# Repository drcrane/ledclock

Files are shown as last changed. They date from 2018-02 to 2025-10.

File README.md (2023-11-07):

LEDCLOCK
========

This repository contains the source files for my seven segment LED
Clock which I made in 2017 for my nephew.

The Clock is powered by an MSP430G2553 and a 32.768 kHz watch
crystal. The clock queried time over the serial port which should
be connected to an ESP8266 (ESP-01) running a modified terminal
programme that supports querying internet time servers.

Running ntpd on Alpine Linux
----------------------------

Turn on a time server in Alpine Linux / busybox (if compiled in)

    busybox ntpd -l -d -d -d -n

This is good for testing as you can see each request for the time.

ESP8266\_RTOS\_SDK
------------------

`esp8266terminal2` uses the espressif SDK, please see readme file
in `esp8266terminal2`.

 - Benjamin Green 2021-12-31

Open-RTOS-SDK
-------------

`esp8266terminal` is no longer used for this project and will be
removed soon. Please use `esp8266terminal2`.

The terminal application was modified (not very well) to support
this application. The REPOs:

repo:   https://github.com/SuperHouse/esp-open-rtos
commit: 46499c0f26c490f5a539f82eb950fa7879f65dc7

repo:   https://github.com/pfalcon/esp-open-sdk
commit: 5518fb6116c35a02ccb9a87260bb194a57cb429e

The build scripts and programmer are required from the above
repos.

The modified terminal application is available in:
`esp8266terminal` I recommend that you copy this into the
`esp-open-rtos/examples` directory to compile and deploy to
an ESP8266.

 - Benjamin Green 2018-02-03

Web Interface Time Setting
--------------------------

To set the time for a clock that currently has an IP address of `192.168.0.128`

    curl -v -d time_to_set=23:50:00 http://192.168.0.128/wifi

A browser may also be used by accessing the page at: `http://192.168.0.128/wifi`.

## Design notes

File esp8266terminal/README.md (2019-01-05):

# Terminal Application

This terminal application contains support for setting the
WiFi SSID and PSK along with the ability to query an arbitrary
internet time server for the current time over serial at 9600.
It was modified for use with the LEDCLOCK project.

## To build this thing....

export PATH=/path_to/esp-open-sdk/xtensa-lx106-elf/bin:$PATH

make ESPPORT=/dev/ttyUSB0 flash

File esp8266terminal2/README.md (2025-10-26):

Terminal Interface for ESP8266 (ESP-01S)
========================================

This is an enhanced version of esp8266terminal which compiles with the
`ESP8266_RTOS_SDK` from espressif.

Setup
-----

To compile the source, download the compiler toolchain:

    xtensa-lx106-elf-gcc8_4_0-esp-2020r3-linux-amd64.tar.gz

And the version of the `ESP8266_RTOS_SDK` you would like to use (for
developing this application version 3.4 was used):

    ESP8266_RTOS_SDK-v3.4.zip

Download URLs:

* [Github Repository RTOS SDK](https://github.com/espressif/ESP8266_RTOS_SDK)
* [xtensa GCC toolchain](https://dl.espressif.com/dl/xtensa-lx106-elf-gcc8_4_0-esp-2020r3-linux-amd64.tar.gz)
* [ESP8266\_RTOS\_SDK](https://github.com/espressif/ESP8266_RTOS_SDK/releases/download/v3.4/ESP8266_RTOS_SDK-v3.4.zip)

Make a workspace directory (for this document ~/esp8266 is assumed) and
extract the contents of the SDK and compiler toolchain:

    mkdir ~/esp8266
    cd ~/esp8266
    # download the files or alter the path as required
    tar -xf xtensa-lx106-elf-gcc8_4_0-esp-2020r3-linux-amd64.tar.gz
    unzip ESP8266_RTOS_SDK-v3.4.zip

Set the required environment variables (this assumes `ash` or `bash`):

    export PATH=~/esp8266/xtensa-lx106-elf/bin:$PATH
    export IDF_PATH=~/esp8266/ESP8266_RTOS_SDK

Now attempt to compile the code:

    cd ~/esp8266/ledclock/esp8266terminal2
    make

This will likely fail since python modules are required

Additional Notes
----------------

`partitions.csv` is a copy of `partitions_singleapp.csv` from the SDK.

Communication using `picocom`
-----------------------------

`picocom` is a useful mini utility that allows serial communication,
it is like minicom but more modern. However, it does not seem to
compile properly on Alpine / musl when one wishes to use custom baud
rates. Custom rates are important for being able to view the early
output sent from an ESP8266 (ESP-01), the device used in my project.

The `setserial` application does work with musl and so to interact
with the device on `/dev/ttyUSB0` at 74880 bps:

    ./setserial /dev/ttyUSB0 74880
    doas ./picocom --noinit --noreset --omap crcrlf /dev/ttyUSB0

`picocom` will probably report that the baud rate is 9600, this can
be safely ignored, the `--noinit` switch will prevent changes to
the rate when the application starts. **IMPORTANT** this also
assumes that the other settings are normal, such as: 8-N-1. That is
to say: 8 data bits, no parity bit and 1 stop bit.

For more detail and to set other options, see the `stty` command.

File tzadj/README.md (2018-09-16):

# Create some Timezone Data for the LED Clock

This is a simple program that creates two numbers per year
the two numbers indicate the start and end of a daylight
saving time in Unix epoch time.

The database is available from:

    https://www.iana.org/time-zones

The one I used is:

    https://data.iana.org/time-zones/releases/tzdb-2018e.tar.lz

## `build.sh`

Running `build.sh` should give this output:

    1711846900 Add an hour? Yes
    2045696401 Add an hour? No
    1887843601 Add an hour? No

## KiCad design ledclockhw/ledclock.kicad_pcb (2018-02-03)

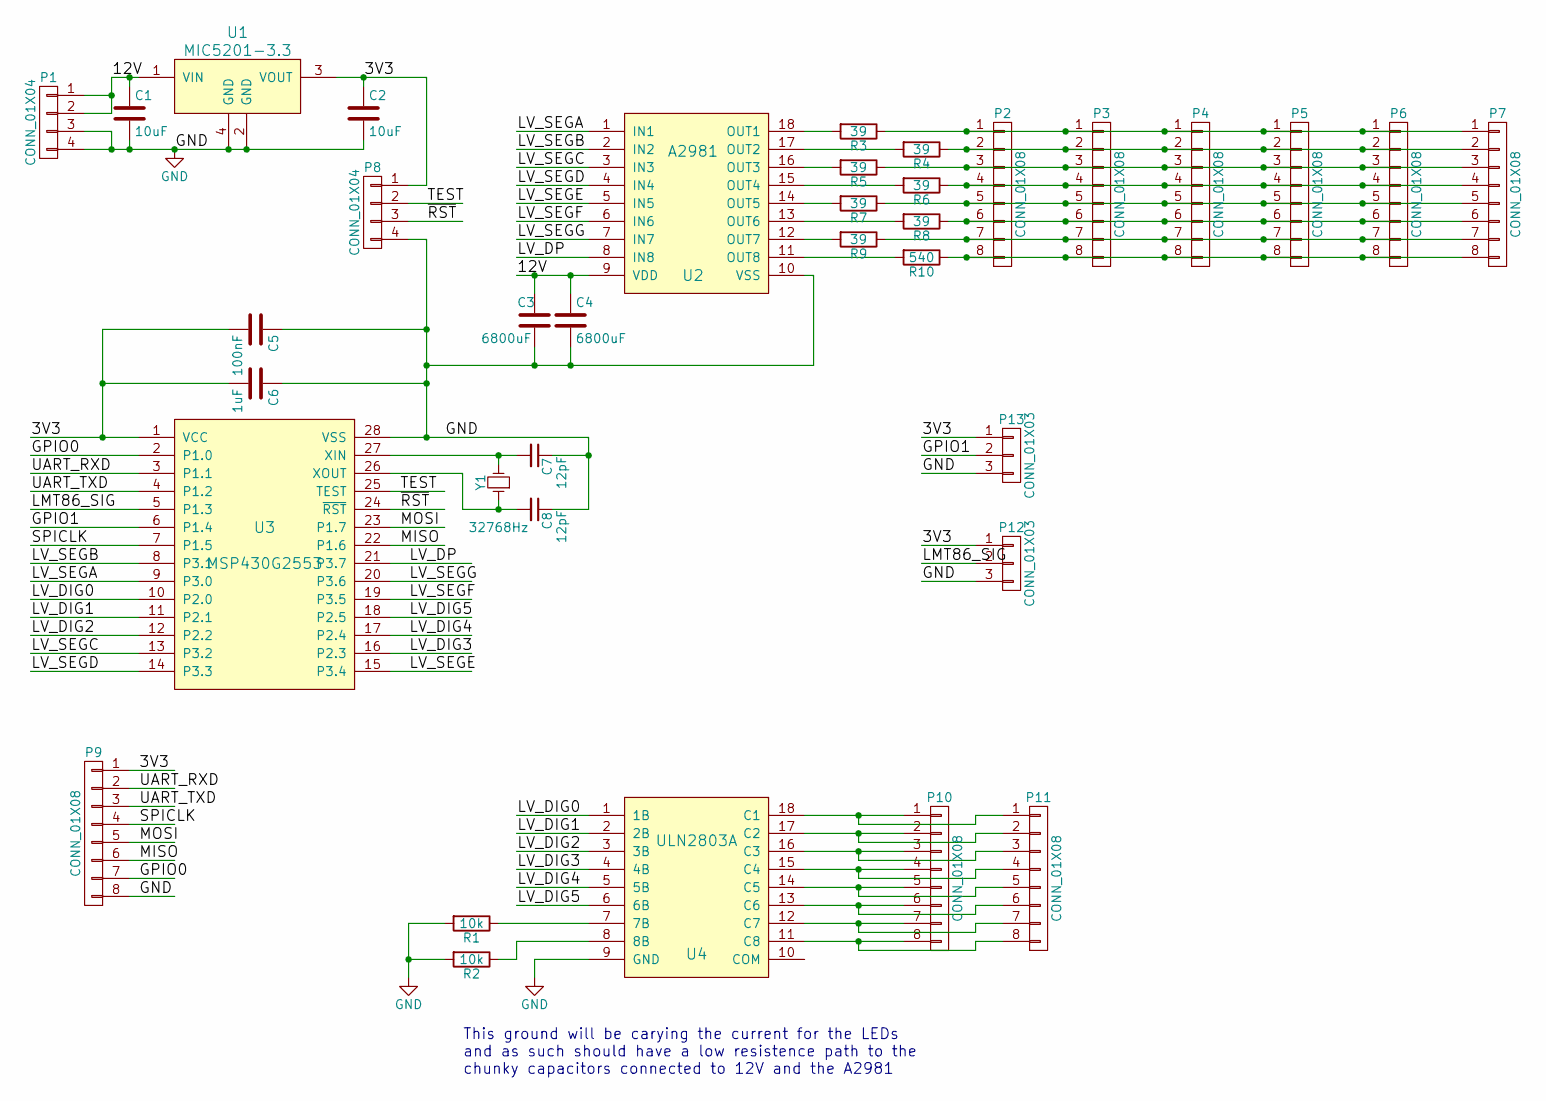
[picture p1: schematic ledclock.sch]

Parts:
C1, C2: 10uF; C_1210
C3, C4: 6800uF; CP_Radial_D18.0mm_P7.50mm
C5: 100nF; C_0603
C6: 1uF; C_0805
C7, C8: 12pF; C_0603
P1, P8: CONN_01X04; Molex_KK-6410-04_04x2.54mm_Straight
P2, P3, P4, P5, P6, P7, P9, P10, P11: CONN_01X08; Molex_KK-6410-08_08x2.54mm_Straight
P12, P13: CONN_01X03; Molex_KK-6410-03_03x2.54mm_Straight
R1, R2: 10k; R_0603
R3, R4, R5, R6, R7, R8, R9: 39; R_1206
R10: 540; R_1206
U1: MIC5201-3.3; SOT-223
U2: A2981; DIP-18_W7.62mm
U3: MSP430G2553; TSSOP-28_4.4x9.7mm_Pitch0.65mm
U4: ULN2803A; DIP-18_W7.62mm
Y1: 32768Hz; Crystal_C38-LF_d3.0mm_l8.0mm_Horizontal

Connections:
/3V3: C2.1, C5.2, C6.2, P8.1, P9.1, P12.1, P13.1, U1.3 (VOUT), U3.1 (VCC)
/12V: C1.1, C3.1, C4.1, P1.1, P1.2, U1.1 (VIN), U2.9 (VDD)
/GPIO0: P9.7, U3.2 (P1.0)
/GPIO1: P13.2, U3.6 (P1.4)
/LMT86_SIG: P12.2, U3.5 (P1.3)
/LV_DIG0: U3.10 (P2.0), U4.1 (1B)
/LV_DIG1: U3.11 (P2.1), U4.2 (2B)
/LV_DIG2: U3.12 (P2.2), U4.3 (3B)
/LV_DIG3: U3.16 (P2.3), U4.4 (4B)
/LV_DIG4: U3.17 (P2.4), U4.5 (5B)
/LV_DIG5: U3.18 (P2.5), U4.6 (6B)
/LV_DP: U2.8 (IN8), U3.21 (P3.7)
/LV_SEGA: U2.1 (IN1), U3.9 (P3.0)
/LV_SEGB: U2.2 (IN2), U3.8 (P3.1)
/LV_SEGC: U2.3 (IN3), U3.13 (P3.2)
/LV_SEGD: U2.4 (IN4), U3.14 (P3.3)
/LV_SEGE: U2.5 (IN5), U3.15 (P3.4)
/LV_SEGF: U2.6 (IN6), U3.19 (P3.5)
/LV_SEGG: U2.7 (IN7), U3.20 (P3.6)
/MISO: P9.6, U3.22 (P1.6)
/MOSI: P9.5, U3.23 (P1.7)
/SPICLK: P9.4, U3.7 (P1.5)
/TEST: P8.2, U3.25 (TEST)
/UART_RXD: P9.2, U3.3 (P1.1)
/UART_TXD: P9.3, U3.4 (P1.2)
/~RST: P8.3, U3.24 (~RST)
GND: C1.2, C2.2, C3.2, C4.2, C5.1, C6.1, C7.1, C8.1, P1.3, P1.4, P8.4, P9.8, P12.3, P13.3, R1.2, R2.2, U1.2 (GND), U1.4 (GND), U2.10 (VSS), U3.28 (VSS), U4.9 (GND)
unnamed: C7.2, U3.27 (XIN), Y1.2
unnamed: C8.2, U3.26 (XOUT), Y1.1
unnamed: P2.1, P3.1, P4.1, P5.1, P6.1, P7.1, R3.1
unnamed: P2.2, P3.2, P4.2, P5.2, P6.2, P7.2, R4.1
unnamed: P2.3, P3.3, P4.3, P5.3, P6.3, P7.3, R5.1
unnamed: P2.4, P3.4, P4.4, P5.4, P6.4, P7.4, R6.1
unnamed: P2.5, P3.5, P4.5, P5.5, P6.5, P7.5, R7.1
unnamed: P2.6, P3.6, P4.6, P5.6, P6.6, P7.6, R8.1
unnamed: P2.7, P3.7, P4.7, P5.7, P6.7, P7.7, R9.1
unnamed: P2.8, P3.8, P4.8, P5.8, P6.8, P7.8, R10.1
unnamed: P10.1, P11.1, U4.18 (C1)
unnamed: P10.2, P11.2, U4.17 (C2)
unnamed: P10.3, P11.3, U4.16 (C3)
unnamed: P10.4, P11.4, U4.15 (C4)
unnamed: P10.5, P11.5, U4.14 (C5)
unnamed: P10.6, P11.6, U4.13 (C6)
unnamed: P10.7, P11.7, U4.12 (C7)
unnamed: P10.8, P11.8, U4.11 (C8)
unnamed: R1.1, U4.7 (7B)
unnamed: R2.1, U4.8 (8B)
unnamed: R3.2, U2.18 (OUT1)
unnamed: R4.2, U2.17 (OUT2)
unnamed: R5.2, U2.16 (OUT3)
unnamed: R6.2, U2.15 (OUT4)
unnamed: R7.2, U2.14 (OUT5)
unnamed: R8.2, U2.13 (OUT6)
unnamed: R9.2, U2.12 (OUT7)
unnamed: R10.2, U2.11 (OUT8)

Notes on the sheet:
This ground will be carying the current for the LEDs and as such should have a low resistence path to the chunky capacitors connected to 12V and the A2981

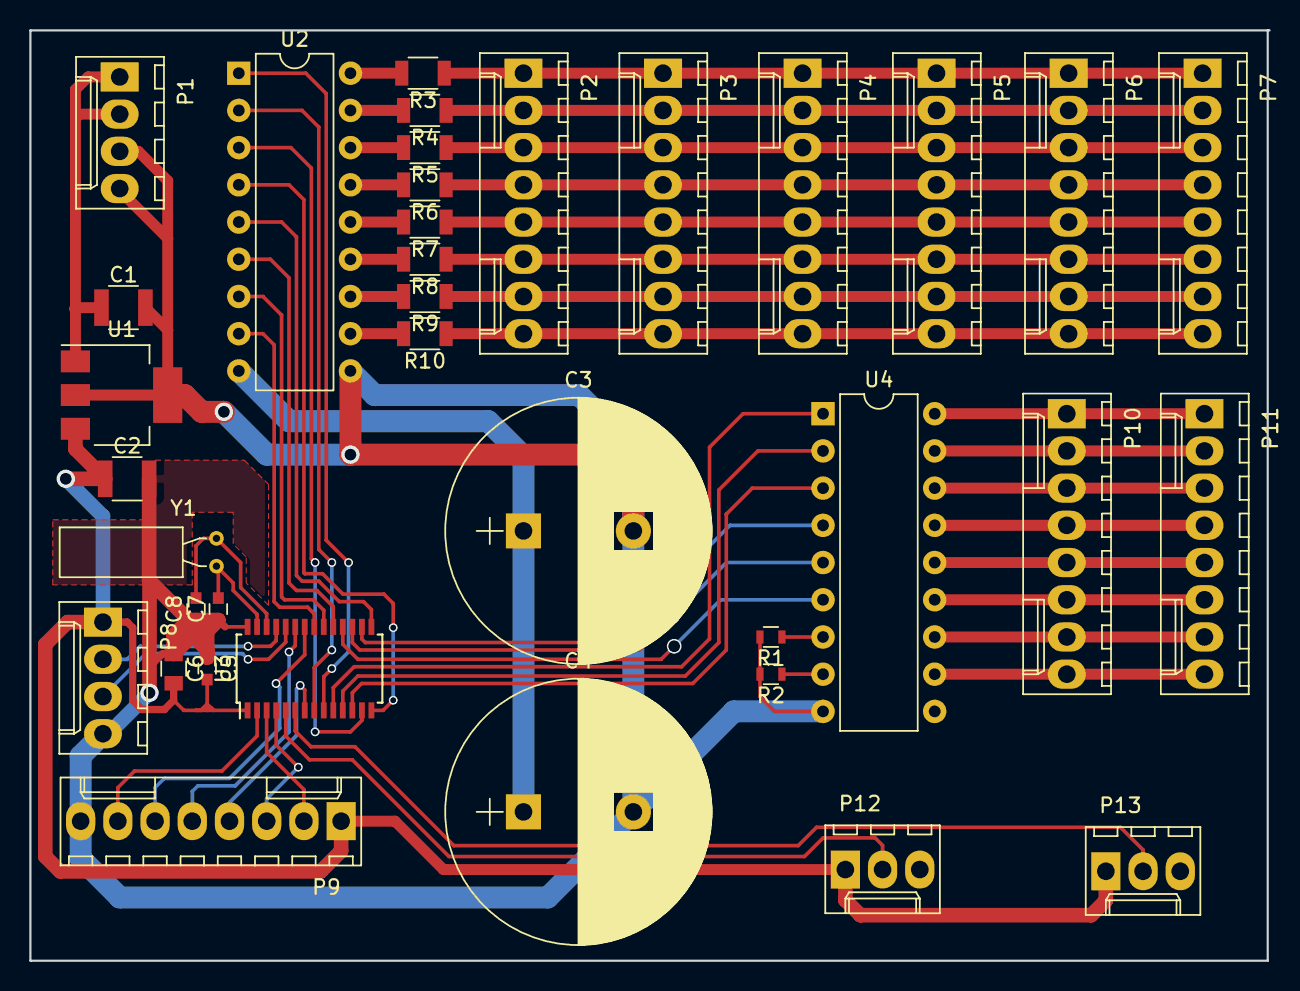
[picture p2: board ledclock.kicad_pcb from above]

Board: 2 copper layers, 84.6 x 63.5 mm, 36 parts (0 on the bottom side), 55 nets.

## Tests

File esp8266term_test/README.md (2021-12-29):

Testing Suite
=============

To run tests for this project the computer must have the standard toolset
installed:

* `make`
* `gcc`
* `valgrind` (optional)
* `busybox`

To compile and run all the tests:

    make test

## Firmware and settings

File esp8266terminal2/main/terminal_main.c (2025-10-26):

/*
   Terminal Interface to ESP8266

   This example code is in the Public Domain (or CC0 licensed, at your option.)

   Unless required by applicable law or agreed to in writing, this
   software is distributed on an "AS IS" BASIS, WITHOUT WARRANTIES OR
   CONDITIONS OF ANY KIND, either express or implied.
*/
#include <stdio.h>
#include <string.h>
#include "freertos/FreeRTOS.h"
#include "freertos/task.h"
#include "freertos/event_groups.h"
#include "esp_system.h"
#include "esp_spi_flash.h"
#include "driver/uart.h"
#include "esp_wifi.h"
#include "esp_event_loop.h"
#include "nvs.h"
#include "nvs_flash.h"
#include "lwip/sockets.h"
#include "lwip/api.h"

#include "argparser.h"

static const char * TAG = "terminal";

static TimerHandle_t system_monitor_timer;

typedef nvs_handle nvs_handle_t;
static nvs_handle_t nvs_config_handle;

static EventGroupHandle_t wifi_event_group;
#define CONNECTED_BIT BIT0
#define CONNECTION_FAILED BIT1

static ip_addr_t sta_ip_addr;
static struct netconn * tcp_server_handle;

static void wifi_event_handler(void * arg, esp_event_base_t event_base, int32_t event_id, void * event_data) {
	if (event_base == WIFI_EVENT) {
		if (event_id == WIFI_EVENT_STA_START) {
			esp_wifi_connect();
		} else
		if (event_id == WIFI_EVENT_STA_DISCONNECTED) {
			// SET CONNECTION FAILED BIT...
			xEventGroupClearBits(wifi_event_group, CONNECTED_BIT);
		}
	} else
	if (event_base == IP_EVENT) {
		if (event_id == IP_EVENT_STA_GOT_IP) {
			ip_event_got_ip_t * ip_event = (ip_event_got_ip_t *)event_data;
			ESP_LOGI(TAG, "got ip: %s", ip4addr_ntoa(&ip_event->ip_info.ip));
			sta_ip_addr = ip_event->ip_info.ip;
			xEventGroupSetBits(wifi_event_group, CONNECTED_BIT);
		}
	}
}

#define WIFI_STA_CONNECTING 1
#define WIFI_STA_CONNECTED 2
#define WIFI_STA_ERROR 4

#define WIFI_AP_ERROR 8

static int wifi_sta_join() {
	esp_err_t rc = ESP_OK;
	wifi_mode_t wifi_mode;
	// Is it already connected?
	int bits = xEventGroupGetBits(wifi_event_group);
	if (bits & CONNECTED_BIT) {
		return WIFI_STA_CONNECTED;
	}
	rc = esp_wifi_get_mode(&wifi_mode);
	if (rc == ESP_OK && !(wifi_mode & WIFI_MODE_STA)) {
		rc = esp_wifi_set_mode(wifi_mode | WIFI_MODE_STA);
	}
	{
		// Is there an ssid set?
		wifi_config_t wifi_config = { 0 };
		size_t len = sizeof(wifi_config.sta.ssid);
		rc = nvs_get_str(nvs_config_handle, "sta.ssid", (char *)(wifi_config.sta.ssid), &len);
		if (rc != ESP_OK) {
			ESP_LOGI(TAG, "sta ssid read error");
			return WIFI_STA_ERROR;
		}
		len = sizeof(wifi_config.sta.password);
		rc = nvs_get_str(nvs_config_handle, "sta.pwd", (char *)wifi_config.sta.password, &len);
		if (rc != ESP_OK) {
			ESP_LOGI(TAG, "sta pwd read error");
			return WIFI_STA_ERROR;
		}
		rc = esp_wifi_set_config(ESP_IF_WIFI_STA, &wifi_config);
		if (rc != ESP_OK) {
			ESP_LOGI(TAG, "sta set config error %d", rc);
			return WIFI_STA_ERROR;
		}
	}
	// begin new connect if wifi was in sta mode otherwise the
	// callback function will perform the connect call
	if (rc == ESP_OK && (wifi_mode & WIFI_MODE_STA)) {
		rc = esp_wifi_connect();
	}
	if (rc != ESP_OK) {
		ESP_LOGI(TAG, "error at end");
		return WIFI_STA_ERROR;
	}
	return WIFI_STA_CONNECTING;
}

static int wifi_softap_start() {
	esp_err_t rc = ESP_OK;
	{
	wifi_config_t wifi_config = { 0 };
	size_t len = sizeof(wifi_config.ap.ssid);
	rc = nvs_get_str(nvs_config_handle, "ap.ssid", (char *)(wifi_config.sta.ssid), &len);
	if (rc != ESP_OK) {
		ESP_LOGI(TAG, "ap ssid read error");
		return WIFI_AP_ERROR;
	}
	}
	//
	return 0;
}

static struct netconn * tcp_client_handle;
static int tcp_client_data_waiting;

static void tcp_server_callback(struct netconn * conn, enum netconn_evt evt, uint16_t length) {
	ESP_LOGI(TAG, "tcp_cb: %d %u", evt, length);
	if (evt == NETCONN_EVT_RCVPLUS) {
		//struct netbuf * netbuf;
		//void * ptr;
		//uint16_t datalen;
		//err_t err;
		if (conn == tcp_server_handle) {
			ESP_LOGI(TAG, "tcp_server_handle");
		} else
		if (conn == tcp_client_handle) {
			//if (length > 0) {
				ESP_LOGI(TAG, "new client data");
				tcp_client_data_waiting ++;
			//}
		} else {
			ESP_LOGI(TAG, "unknown client data");
			tcp_client_data_waiting ++;
		}
		// Don't think can call in callback.
		//err = netconn_accept(conn, &tcp_client_handle);
		//ESP_LOGI(TAG, "netconn_accept err = %d", err);
		/*
		if (conn == tcp_server_handle && netconn_accept(conn, &tcp_client_handle) == ERR_OK) {
			ESP_LOGI(TAG, "got new connection");
		} else
		if (conn == tcp_client_handle && netconn_recv(conn, &netbuf) == ERR_OK) {
			ESP_LOGI(TAG, "recv_ok");
			do {
				netbuf_data(netbuf, (void *)&ptr, &datalen);
				ESP_LOGI(TAG, "%d", (int)datalen);
			} while (netbuf_next(netbuf) >= 0);
			netbuf_delete(netbuf);
		} else {
			ESP_LOGI(TAG, "got something %d %u", (int)evt, length);
		}
		*/
	}
}

static void system_monitor_callback(TimerHandle_t xTimer) {
	int rc = wifi_sta_join();
	{
		char buf[32];
		sprintf(buf, "wifi_sta_join() %d\r\n", rc);
		uart_write_bytes(UART_NUM_0, buf, strlen(buf));
	}
	if (rc == WIFI_STA_CONNECTED) {
		err_t err;
		struct netbuf * netbuf;
		void * ptr;
		uint16_t datalen;
		if (tcp_server_handle == NULL) {
			// begin listening
			// esp_err_t tcpip_adapter_get_ip_info(tcpip_adapter_if_t tcpip_if, tcpip_adapter_ip_info_t *ip_info);
			//ip_addr_t ip_any = IP_ADDR_ANY;
			tcp_server_handle = netconn_new_with_callback(NETCONN_TCP, tcp_server_callback);
			ESP_LOGI(TAG, "%d", tcp_server_handle == NULL ? 0 : 1);
			netconn_set_flags(tcp_server_handle, NETCONN_FLAG_NON_BLOCKING);
			// Don't need to use htons here... for some reason.
			err = netconn_bind(tcp_server_handle, IP_ADDR_ANY, 5000);
			ESP_LOGI(TAG, "bind err %d", err);
			err = netconn_listen_with_backlog(tcp_server_handle, 2);
			ESP_LOGI(TAG, "listen err %d", err);
			tcp_client_handle = NULL;
		}
		if (tcp_server_handle != NULL) {
			struct netconn * client_conn;
			err = netconn_accept(tcp_server_handle, &client_conn);
			if (err == ERR_WOULDBLOCK) {
				ESP_LOGI(TAG, "would block here");
			} else
			if (err == ERR_OK) {
				tcp_client_data_waiting = 0;
				tcp_client_handle = client_conn;
				ESP_LOGI(TAG, "accepted connection");
			} else {
				ESP_LOGI(TAG, "netconn_accept err = %d", err);
				if (tcp_client_handle) {
					netconn_delete(tcp_client_handle);
					tcp_client_handle = NULL;
				}
			}
		}
		if (tcp_client_handle) {
			ESP_LOGI(TAG, "accept complete");
			if (tcp_client_data_waiting) {
				ESP_LOGI(TAG, "data waiting");
				if ((err = netconn_recv(tcp_client_handle, &netbuf)) == ERR_OK) {
					do {
						netbuf_data(netbuf, (void **)&ptr, &datalen);
						ESP_LOGI(TAG, "got data %d", (int)datalen);
					} while (netbuf_next(netbuf) >= 0);
					netbuf_delete(netbuf);
				//	tcp_client_data_waiting = 0;
				//} else
				//if (err == ERR_WOULDBLOCK) {
				//	ESP_LOGI(TAG, "still connected");
				//} else {
				//	ESP_LOGI(TAG, "connection closed");
				//	netconn_close(tcp_client_handle);
					//	netconn_delete(tcp_client_handle);
				//	tcp_client_handle = NULL;
				//	tcp_client_data_waiting --;
				} else {
					ESP_LOGI(TAG, "recv err = %d", err);
					netconn_close(tcp_client_handle);
					netconn_delete(tcp_client_handle);
					tcp_client_handle = NULL;
					//tcp_client_data_waiting = 0;
				}
				tcp_client_data_waiting --;
			}
		}
	}
	/*
	switch (rc) {
	case WIFI_RC_CONNECTING:
	case WIFI_RC_CONNECTED:
	case WIFI_RC_ERROR:
	default:
	}
	*/
}

static void command_process(int argc, char *argv[]) {
	esp_err_t err;
	if (strcmp(argv[0], "wifi") == 0) {
		//if (argc >= 3 && strcmp(argv[1], "config") == 0) {
			//if (strcmp(argv[2], "dump") == 0) {
			//	wifi_config_t config = {0};
			//	err = esp_wifi_get_config(ESP_IF_WIFI_STA, &config);
			//	if (err != ESP_OK) {
			//		uart_write_bytes(UART_NUM_0, "ERR\r\n", 5);
			//		return;
			//	}
			//	uart_write_bytes(UART_NUM_0, (char *)config.sta.ssid, strlen((char *)config.sta.ssid));
			//	uart_write_bytes(UART_NUM_0, "\r\n", 2);
			//}
		//} else
		if (strcmp(argv[1], "join") == 0) {
			wifi_sta_join();
			//int timeout_ms = 10000;
			//wifi_mode_t wifi_mode = WIFI_MODE_NULL;
			//if (esp_wifi_get_mode(&wifi_mode) == ESP_OK && wifi_mode != WIFI_MODE_STA && wifi_mode != WIFI_MODE_APSTA) {
			//	ESP_ERROR_CHECK(esp_wifi_set_mode(WIFI_MODE_STA));
			//} else {
			//}
			//if (argc == 4) {
			//	//strncpy((char *)wifi_config.sta.ssid, argv[2], sizeof(wifi_config.sta.ssid));
			//	//strncpy((char *)wifi_config.sta.password, argv[3], sizeof(wifi_config.sta.password));
			//	//ESP_ERROR_CHECK(esp_wifi_set_config(ESP_IF_WIFI_STA, &wifi_config));
			//}
			//if (wifi_mode == WIFI_MODE_STA || wifi_mode == WIFI_MODE_APSTA) {
			//	ESP_ERROR_CHECK(esp_wifi_connect());
			//} else {
			//}
			//int bits = xEventGroupWaitBits(wifi_event_group, CONNECTED_BIT,
			//		pdFALSE, pdFALSE, timeout_ms / portTICK_PERIOD_MS);
			//if (bits & CONNECTED_BIT) {
			//	uart_write_bytes(UART_NUM_0, "CON\r\n", 5);
			//} else {
			//	uart_write_bytes(UART_NUM_0, "TOC\r\n", 5);
			//}
		} else
		if (strcmp(argv[1], "status") == 0) {
			int bits = xEventGroupGetBits(wifi_event_group);
			if (bits & CONNECTED_BIT) {
				uart_write_bytes(UART_NUM_0, "CON\r\n", 5);
			} else {
				uart_write_bytes(UART_NUM_0, "DIS\r\n", 5);
			}
		} else
		if (argc == 4 && strcmp(argv[1], "on") == 0) {
			uart_write_bytes(UART_NUM_0, "wifion?\r\n", 9);
		} else {
			uart_write_bytes(UART_NUM_0, "eh?\r\n", 5);
		}
	} else
	if (strcmp(argv[0], "set") == 0) {
		/*
		if (argc == 3) {
		if (strcmp(argv[1], "ssid") == 0) {
		}
		if (strcmp(argv[1], "pwd") == 0) {
		}
		}
		*/
		if (argc == 4) {
			if (strcmp(argv[1], "stacred") == 0) {
				err = nvs_set_str(nvs_config_handle, "sta.ssid", argv[2]);
				if (err == ESP_OK) {
					err = nvs_set_str(nvs_config_handle, "sta.pwd", argv[3]);
				}
				if (err == ESP_OK) {
					uart_write_bytes(UART_NUM_0, "OK_\r\n", 5);
				} else {
					uart_write_bytes(UART_NUM_0, "ERR\r\n", 5);
				}
			} else
			if (strcmp(argv[1], "apcred") == 0) {
				err = nvs_set_str(nvs_config_handle, "ap.ssid", argv[2]);
				if (err == ESP_OK) {
					err = nvs_set_str(nvs_config_handle, "ap.pwd", argv[3]);
				}
				if (err == ESP_OK) {
					uart_write_bytes(UART_NUM_0, "OK_\r\n", 5);
				} else {
					uart_write_bytes(UART_NUM_0, "ERR\r\n", 5);
				}
			}
		}
	} else
	if (strcmp(argv[0], "get") == 0) {
		if (argc == 1) {
			size_t len = 32;
			char buf[32];
			uart_write_bytes(UART_NUM_0, "STA\r\n", 5);
			err = nvs_get_str(nvs_config_handle, "sta.ssid", buf, &len);
			if (err == ESP_OK) {
				uart_write_bytes(UART_NUM_0, buf, len);
				uart_write_bytes(UART_NUM_0, "\r\n", 2);
			}
			len = 32;
			err = nvs_get_str(nvs_config_handle, "sta.pwd", buf, &len);
			if (err == ESP_OK) {
				uart_write_bytes(UART_NUM_0, buf, len);
				uart_write_bytes(UART_NUM_0, "\r\n", 2);
			}
			uart_write_bytes(UART_NUM_0, "AP_\r\n", 5);
		}
		if (argc == 2) {
			if (strcmp(argv[1], "stacred") == 0) {
				size_t len = 29;
				char buf[32];
				err = nvs_get_str(nvs_config_handle, "sta.ssid", buf, &len);
				if (err == ESP_OK) {
					strcat(buf, "\r\n");
					len = strlen(buf);
					uart_write_bytes(UART_NUM_0, buf, len);
					len = 29;
					err = nvs_get_str(nvs_config_handle, "sta.pwd", buf, &len);
				}
				if (err == ESP_OK) {
					strcat(buf, "\r\n");
					len = strlen(buf);
					uart_write_bytes(UART_NUM_0, buf, len);
				} else {
					uart_write_bytes(UART_NUM_0, "ERR\r\n", 5);
				}
			}
		}
	} else
	if (strcmp(argv[0], "unset") == 0) {
		//xEventGroupClearBits(wifi_event_group, CONNECTED_BIT);
	}
}

/**
 * This is an example which echos any data it receives on UART0 back to the sender,
 * with hardware flow control turned off. It does not use UART driver event queue.
 *
 * - Port: UART0
 * - Receive (Rx) buffer: on
 * - Transmit (Tx) buffer: off
 * - Flow control: off
 * - Event queue: off
 */

#define BUF_SIZE (1024)

static void command_task() {
	uint8_t * pos;
	uint8_t * data;
	char * arg[ARGPARSER_MAXARGS];
	int arg_count;
	// Configure parameters of an UART driver,
	// communication pins and install the driver
	uart_config_t uart_config = {
		.baud_rate = 74880,
		.data_bits = UART_DATA_8_BITS,
		.parity    = UART_PARITY_DISABLE,
		.stop_bits = UART_STOP_BITS_1,
		.flow_ctrl = UART_HW_FLOWCTRL_DISABLE
	};
	uart_param_config(UART_NUM_0, &uart_config);
	uart_driver_install(UART_NUM_0, BUF_SIZE * 2, 0, 0, NULL, 0);

	// Configure a temporary buffer for the incoming data
	data = (uint8_t *) malloc(BUF_SIZE);
	pos = data;

	// Disable Buffering (used for printf)
	//setvbuf(stdin, NULL, _IONBF, 0);
	//setvbuf(stdout, NULL, _IONBF, 0);
	while (1) {
		// Read data from the UART
		int len = uart_read_bytes(UART_NUM_0, pos, BUF_SIZE, 20 / portTICK_RATE_MS);
		// Write data back to the UART
		uart_write_bytes(UART_NUM_0, (const char *)pos, len);

		if (len > 0) {
			pos = pos + len;
			len = argparser_check_for_eol((char *)data, (char *)pos);
			if (len) {
				arg_count = argparser_parse(arg, (char *)data);
				command_process(arg_count, arg);
				pos = data;
			}
		}
	}
}

static void initialise_nvs() {
	esp_err_t err = nvs_flash_init();
	if (err == ESP_ERR_NVS_NO_FREE_PAGES) {
		ESP_ERROR_CHECK(nvs_flash_erase());
		err = nvs_flash_init();
	}
	ESP_ERROR_CHECK(err);
	err = nvs_open("config", NVS_READWRITE, &nvs_config_handle);
	ESP_ERROR_CHECK(err);
}

static void initialise_wifi() {
	tcpip_adapter_init();
	wifi_event_group = xEventGroupCreate();
	//ESP_ERROR_CHECK(esp_event_loop_init(wifi_event_handler, NULL));

	ESP_ERROR_CHECK(esp_event_loop_create_default());
	ESP_ERROR_CHECK(esp_event_handler_register(WIFI_EVENT, ESP_EVENT_ANY_ID, &wifi_event_handler, NULL));
	ESP_ERROR_CHECK(esp_event_handler_register(IP_EVENT, IP_EVENT_STA_GOT_IP, &wifi_event_handler, NULL));

	wifi_init_config_t cfg = WIFI_INIT_CONFIG_DEFAULT();
	ESP_ERROR_CHECK(esp_wifi_init(&cfg));
	// Allowing the wifi library to save state to fash causes an LoadStoreAlignment exception
	// TODO: Investigate the error further.
	ESP_ERROR_CHECK(esp_wifi_set_storage(WIFI_STORAGE_RAM));
	ESP_ERROR_CHECK(esp_wifi_set_mode(WIFI_MODE_NULL));
	ESP_ERROR_CHECK(esp_wifi_start());

	tcp_server_handle = NULL;
}

void app_main() {
	initialise_nvs();
	initialise_wifi();
	xTaskCreate(command_task, "command_task", 1024, NULL, 10, NULL);
	system_monitor_timer = xTimerCreate("system_monitor", 10000 / portTICK_RATE_MS, pdTRUE, (void *)0, &system_monitor_callback);
	xTimerStart(system_monitor_timer, 0);
}

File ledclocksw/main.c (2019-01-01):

#include <msp430.h>
#include <stdint.h>
#include <stddef.h>
#include <string.h>

#include "utilityfn.h"
#include "timerfn.h"
#include "rtc.h"
#include "usc.h"

const char digits[] = { 0xBF, 0x06, 0x5B, 0x4F, 0xE6, 0xED, 0xFD, 0x07, 0xFF, 0xEF, 0x99, 0xE3 };

void outputdigit(void * ptr) {
	char dst[8];
	Utility_intToHex(dst, ptr, 1);
	hwuart_sendstr(dst);
}

void printtime() {
	outputdigit(&rtcctx.hours);
	outputdigit(&rtcctx.minutes);
	outputdigit(&rtcctx.seconds);
	hwuart_sendstr("\r\n");
	//hwuart_sendstr("lwl");
}

int digit_idx;

void Timer1_A0(void) __attribute__((interrupt(TIMER1_A0_VECTOR)));
void Timer1_A0(void) {
	//P2OUT = 1;
	//P3OUT = digits[digit_idx];
}

#define TA_IFG        0x0a
#define TA_CCR1_MATCH 0x02
#define TA_CCR2_MATCH 0x04

void Timer1_A1(void) __attribute__((interrupt(TIMER1_A1_VECTOR)));
void Timer1_A1(void) {
	int digit_bitmap_idx;
	int p2val;
	// Interrupt Flag is cleared by reading TA1IV
	switch (TA1IV) {
	// Mark Period
	case TA_CCR1_MATCH:
		if (1) {
		switch (digit_idx) {
		case 0:
		{
			if (rtcctx.hours != 0) {
				digit_bitmap_idx = rtcctx.hours / 10;
			} else {
				digit_bitmap_idx = 0;
			}
			digit_idx ++;
			p2val = 0x01;
		}
		break;
		case 1:
		{
			if (rtcctx.hours != 0) {
				digit_bitmap_idx = rtcctx.hours % 10;
			} else {
				digit_bitmap_idx = 0;
			}
			digit_idx ++;
			p2val = 0x02;
		}
		break;
		case 2:
		{
			if (rtcctx.minutes != 0) {
				digit_bitmap_idx = (rtcctx.minutes / 10) % 10;
			} else {
				digit_bitmap_idx = 0;
			}
			digit_idx ++;
			p2val = 0x04;
		}
		break;
		default:
		{
			digit_bitmap_idx = rtcctx.minutes % 10;
			digit_idx = 0;
			p2val = 0x08;
		}
		//
		break;
		}
		P3OUT = digits[digit_bitmap_idx];
		P2OUT = p2val;
		//
		} else {
			// INITIALISING...
		}
		break;
	case TA_IFG:
	default:
	{
		P2OUT = 0;
	}
	break;
	}
}

uint16_t i;

int main() __attribute__ ((naked));
int main() {
	WDTCTL = WDTPW | WDTHOLD;

	BCSCTL1 = CALBC1_8MHZ;
	DCOCTL = CALDCO_8MHZ;

	// Hold MCP23017 in RESET (P3.7)
	P3OUT &= ~(BIT7 | BIT6 | BIT5);
	P3DIR |= BIT7 | BIT6 | BIT5;

	// Initialise the UART 9600 @ 8MHz
	P1SEL |= BIT1 | BIT2;
	P1SEL2 |= BIT1 | BIT2;
	UCA0CTL1 |= UCSSEL_2 | UCSWRST;
	UCA0BR0 = 52;
	UCA0BR1 = 0;
	UCA0MCTL = UCBRF_3 | UCOS16;
	UCA0CTL1 &= ~UCSWRST;

	IFG2 &= ~UCA0RXIFG;
	IE2 |= UCA0RXIE;

	hwuart_init();

	// Initialise the Clock / Timer
	//TA0CTL = //
	BCSCTL3 |= XCAP_3; // 12.5pF Load on XTAL
	// TASSEL_1  - SELECT ACLK
	// ID_0      - DIVIDE BY 1
	// MC_1      - COUNT UP TO TA0CCR0
	// TACLR     - CLEAR THE TA0CR REGISTER
	// TAIE      - ENABLE INTERRUPTS
	TA0CTL = TASSEL_1 | ID_0 | MC_1 | TACLR; // | TAIE;
	// ONE SECOND INTERRUPTS
	TA0CCR0 = 32767;
	TA0CCTL0 = CCIE;

	UCA0TXBUF = 'I';
	while(!(IFG2 & UCA0TXIFG)) { __nop(); }

	// Turn LED ON on Demo Board
	P1DIR |= BIT0;
	P1OUT &= ~BIT0;

	P3OUT = 0x0;
	P3DIR = 0xFF;

	P2OUT = 0x2 | 0x8;
	P2DIR = 0xFF;

	// ID_3 is clock /8
	// 1 cycle @ 8MHz = 0.125uS, tick once per mS: 1000.0/(0.125*8.0) = 1000
	TA1CTL = ID_3 | TASSEL_2 | MC_1 | TACLR | TAIE;
	TA1CCR0 = 2000;
	TA1CCR1 = 50;
	TA1CCTL0 = CCIE;
	TA1CCTL1 = CCIE;

	digit_idx = 0;

	rtc_initialise();
	//printtime();

	i = 65530; while (i--) { __nop(); }

	__bis_SR_register(GIE);
	__nop();

	while (1) {
		if (hwuart_flags & HWUART_HASRECEIVED) {
			// Toggle on received byte
			P1OUT ^= BIT0;
			hwuart_flags &= ~HWUART_HASRECEIVED;
			int8_t * lb = hwuart_getlinebuf();
			if (*lb == 'p') {
				printtime();
			} else
			if (strncmp((char *)lb, "TIME", 4) == 0) {
				rtcctx.hours = Utility_aToInt((char *)lb + 4);
				rtcctx.minutes = Utility_aToInt((char *)lb + 7);
				rtcctx.seconds = Utility_aToInt((char *)lb + 10);
				//printtime();
				rtcctx.flags |= RTCFLAGS_TIMESET;
			}
			//UCA0TXBUF = hwuart_byte;
		}
		if (rtcctx.flags & RTCFLAGS_UPDATETIME) {
			hwuart_sendstr("\rtime sync beverly.bengreen.eu\r");
			rtcctx.flags &= ~RTCFLAGS_UPDATETIME;
		}
		//P3OUT = digits[rtcctx.seconds % 10];

		//timer_docallbacks();
	}
}
